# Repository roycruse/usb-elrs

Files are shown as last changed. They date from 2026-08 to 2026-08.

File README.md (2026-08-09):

# USB ELRS Receiver Dongle

> Transform an **ExpressLRS (ELRS) Receiver** and a **Seeed Studio XIAO nRF52840** into a high-speed, zero-latency USB HID Gamepad dongle for PC and laptop FPV simulators.

---

## 📌 Overview

This project turns a compact ELRS receiver (such as the Foxeer Lite ELRS RX) and a Seeed Studio XIAO nRF52840 into a permanent, plug-and-play USB HID joystick for FPV simulators (VelociDrone, Liftoff, Uncrashed, Tryp FPV, DCL, etc.).

Once plugged into your PC or laptop, it sits quietly in the background and automatically connects whenever you turn on your radio transmitter.

---

## ✨ Features

- ⚡ **Ultra-Fast Polling (1000 Hz / 1ms)**: Configured with `Adafruit_TinyUSB` for 1ms USB HID report intervals for minimum latency.
- 📡 **420k Baud CRSF Support**: Direct hardware register timing overrides (`NRF_UARTE0->BAUDRATE`) for exact 420,000 baud CRSF protocol parsing via `AlfredoCRSF`.
- 🎛️ **Full Radio Control Support (Optimized for Radiomaster GX12 / TX16S / Boxer / Pocket)**:
  - **4 Axis Sticks**: Roll, Pitch, Throttle, Yaw (CH1–CH4)
  - **2 Sliders/Dials**: S1, S2 (CH5–CH6)
  - **4 Toggle & Momentary Switches**: SA, SD, SG, SH (CH7–CH10 → HID Buttons 1–4)
  - **4 Cumulative 3-Position Switches**: SE, SB, SC, SF (CH11–CH14 → HID Buttons 5–12)
- 🟢 **Link Status LED**: Built-in green LED lights up solid when the ELRS receiver link is active.
- 🪶 **Compact & Antenna-Free**: Uses compact receiver models (like Foxeer Lite ELRS with onboard ceramic antenna) so no long external dipoles get in the way.

---

## 🛠️ Hardware Requirements

| Component | Recommendation | Notes |
| :--- | :--- | :--- |
| **Microcontroller** | Seeed Studio XIAO nRF52840 | Native USB stack & fast hardware UART |
| **ELRS Receiver** | Foxeer Lite ELRS RX (or similar) | Integrated SMD ceramic antenna; ideal for desk/room range |
| **Wiring** | 4-wire connection | Power, Ground, TX, RX |

---

## 🔌 Wiring & Pinout

Connect the ELRS receiver to the XIAO nRF52840 as follows:

| Seeed XIAO nRF52840 Pin | ELRS Receiver Pin | Description |
| :---: | :---: | :--- |
| **5V / 3V3** | **VCC** | Power Supply |
| **GND** | **GND** | Ground |
| **D5** | **TX** | XIAO Serial1 RX $\leftarrow$ Receiver TX |
| **D6** | **RX** | XIAO Serial1 TX $\rightarrow$ Receiver RX |

### 🖼️ Circuit Diagrams

<div align="center">

#### Top Side Soldering Layout
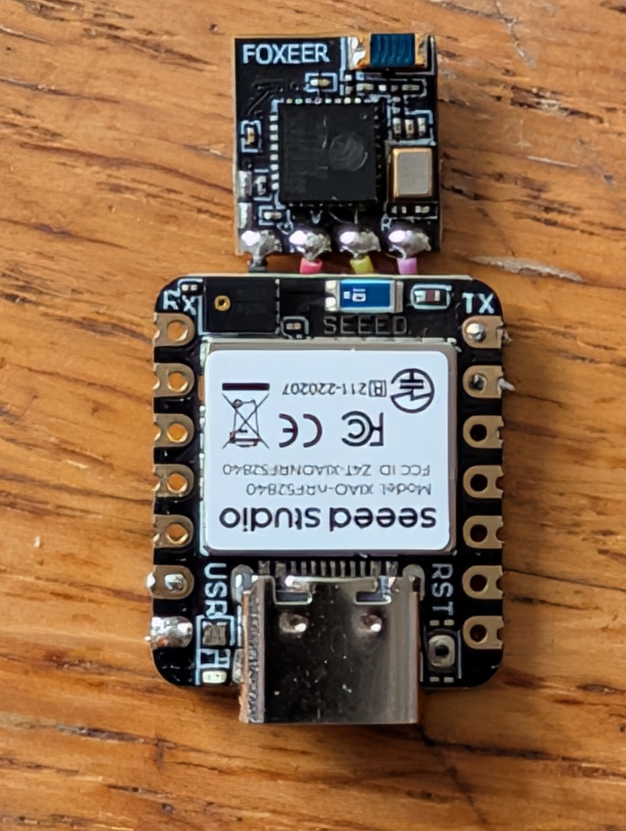
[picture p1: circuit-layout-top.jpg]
Circuit Layout Top


#### Bottom Side Soldering Layout
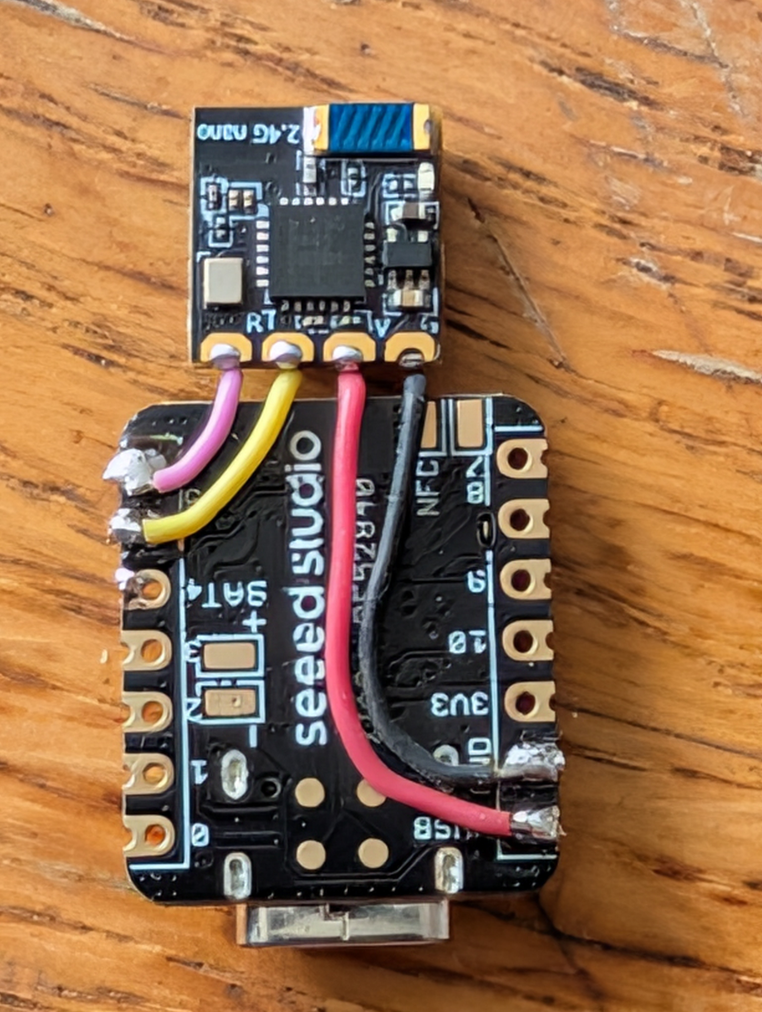
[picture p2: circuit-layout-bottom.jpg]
Circuit Layout Bottom


</div>

---

## 🕹️ Channel Mapping

| Channel | Radio Input | HID Mapping | Description |
| :---: | :---: | :---: | :--- |
| **CH1** | Roll | `X` Axis | Stick Roll (-127 to 127) |
| **CH2** | Pitch | `Y` Axis | Stick Pitch (-127 to 127) |
| **CH3** | Throttle | `Z` Axis | Stick Throttle (-127 to 127) |
| **CH4** | Yaw | `Rz` Axis | Stick Yaw (-127 to 127) |
| **CH5** | Slider S1 | `Rx` Axis | Auxiliary Slider 1 |
| **CH6** | Slider S2 | `Ry` Axis | Auxiliary Slider 2 |
| **CH7** | Switch SA | Button 1 | Toggle / Momentary Switch |
| **CH8** | Switch SD | Button 2 | Toggle / Momentary Switch |
| **CH9** | Switch SG | Button 3 | Toggle / Momentary Switch |
| **CH10** | Switch SH | Button 4 | Toggle / Momentary Switch |
| **CH11** | Switch SE | Buttons 5 & 6 | Cumulative 3-Pos Switch |
| **CH12** | Switch SB | Buttons 7 & 8 | Cumulative 3-Pos Switch |
| **CH13** | Switch SC | Buttons 9 & 10 | Cumulative 3-Pos Switch |
| **CH14** | Switch SF | Buttons 11 & 12 | Cumulative 3-Pos Switch |

> [!NOTE]
> **3-Position Switch Logic**:
> - **Pushed Away** (`< 1300µs`): Both buttons OFF
> - **Middle Position** (`1300µs – 1700µs`): Button A ON
> - **Pulled Near** (`> 1700µs`): Button A ON + Button B ON

---

## 💻 Software Setup

### Prerequisites

1. **Arduino IDE** (v2.x recommended)
2. **Seeed nRF52840 Board Support**:
   - Add Seeed nRF52840 package via Arduino Board Manager (`Seeed nRF52840 Boards`).
3. **Required Libraries**:
   - `Adafruit TinyUSB Library`
   - `AlfredoCRSF`

### Flashing

1. Select Board: **Seeed XIAO nRF52840**
2. Select USB Stack: **Adafruit TinyUSB** (*Tools > USB Stack > Adafruit TinyUSB*)
3. Open [`usb-elrs-seed-xiao-nrf52840.ino`](usb-elrs-seed-xiao-nrf52840.ino)
4. Compile and Upload!

---

## 📦 3D Printed Case & Enclosure Design

A custom 2-part protective enclosure is included in this repository to neatly house both the Seeed Studio XIAO nRF52840 and the ELRS receiver.

### Included CAD & 3D Model Files

| File | Description | Format |
| :--- | :--- | :---: |
| [`usb elrs case.f3d`](usb%20elrs%20case.f3d) | Autodesk Fusion 360 Master Parametric CAD File | `.f3d` |
| [`usb elrs case top.3mf`](usb%20elrs%20case%20top.3mf) | Top Enclosure Cover | `.3mf` |
| [`usb elrs case bottom.3mf`](usb%20elrs%20case%20bottom.3mf) | Bottom Main Housing Base | `.3mf` |

### 🖨️ Recommended Print Settings

- **Layer Height**: `0.16mm` or `0.20mm`
- **Infill**: `15% – 20%` (Gyroid or Grid)
- **Material**: PLA, PETG, or ABS/ASA
- **Supports**: None needed when printed flat on the bed

---

## 🚀 Project Status & Roadmap

- [x] High-speed 1ms USB HID joystick code for Seeed XIAO nRF52840
- [x] Full CRSF 14-channel stick, slider & switch mapping
- [x] Hardware register timing overrides for 420k baud CRSF
- [x] Custom 3D-printed protective enclosure (`.f3d` CAD source & `.3mf` models)

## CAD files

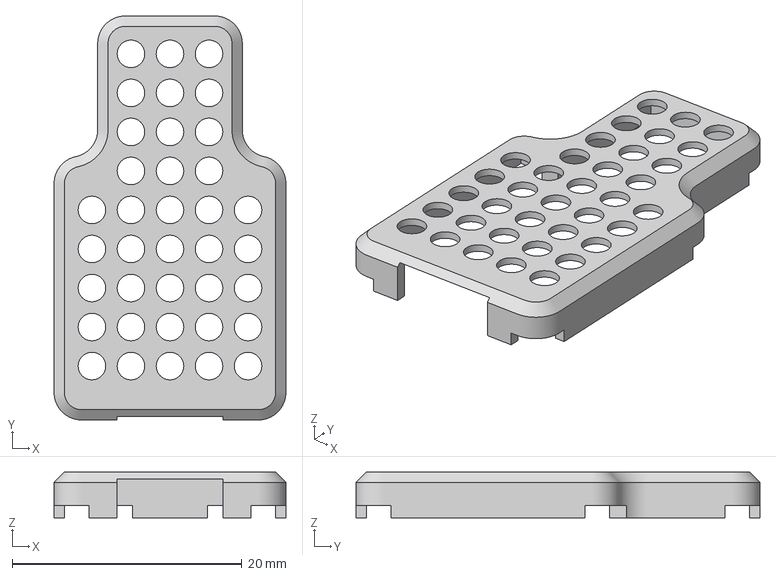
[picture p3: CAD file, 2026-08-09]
usb elrs case top.3mf
20.2 x 35.2 x 4.00 mm

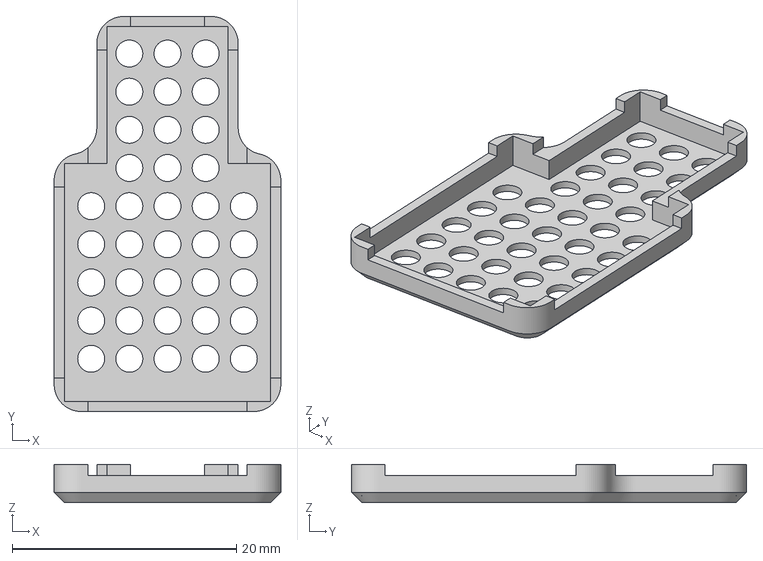
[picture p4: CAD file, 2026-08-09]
usb elrs case bottom.3mf
20.2 x 35.2 x 3.40 mm

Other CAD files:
usb elrs case.f3d

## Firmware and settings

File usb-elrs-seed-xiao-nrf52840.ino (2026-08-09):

#include <Arduino.h>
#include <Adafruit_TinyUSB.h>
#include <AlfredoCRSF.h>

// Standard Gamepad HID Descriptor
uint8_t const desc_hid_report[] = {
  TUD_HID_REPORT_DESC_GAMEPAD()
};

Adafruit_USBD_HID usb_hid;

typedef struct ATTR_PACKED {
  int8_t  x;         // CH1: Roll
  int8_t  y;         // CH2: Pitch
  int8_t  z;         // CH3: Throttle
  int8_t  rz;        // CH4: Yaw
  int8_t  rx;        // CH5: Slider S1
  int8_t  ry;        // CH6: Slider S2
  uint8_t hat;       // Hat switch (0 = centered)
  uint32_t buttons;  // Bitfield for Buttons 1-12 (CH7-CH14)
} hid_custom_gamepad_report_t;

hid_custom_gamepad_report_t gp;
AlfredoCRSF crsf;

void setup() {
  pinMode(LED_GREEN, OUTPUT);
  digitalWrite(LED_GREEN, HIGH); // Off initially

  // Ultra-fast 1ms USB HID polling rate
  usb_hid.setPollInterval(1);
  usb_hid.setReportDescriptor(desc_hid_report, sizeof(desc_hid_report));
  usb_hid.begin();

  // Hardware UART on D5 (RX) / D6 (TX)
  Serial1.setPins(D5, D6);
  Serial1.begin(420000);
  NRF_UARTE0->BAUDRATE = 0x06B50000; // Exact 420k timing override

  crsf.begin(Serial1);
  memset(&gp, 0, sizeof(gp));
}

void loop() {
  crsf.update();

  if (crsf.isLinkUp()) {
    digitalWrite(LED_GREEN, LOW); // Green LED ON solid when linked

    // --- 1. STICKS (CH1 - CH4) ---
    gp.x  = (int8_t)map(constrain(crsf.getChannel(1), 988, 2012), 988, 2012, -127, 127);
    gp.y  = (int8_t)map(constrain(crsf.getChannel(2), 988, 2012), 988, 2012, -127, 127);
    gp.z  = (int8_t)map(constrain(crsf.getChannel(3), 988, 2012), 988, 2012, -127, 127);
    gp.rz = (int8_t)map(constrain(crsf.getChannel(4), 988, 2012), 988, 2012, -127, 127);

    // --- 2. SLIDERS / DIALS (CH5 & CH6) ---
    gp.rx = (int8_t)map(constrain(crsf.getChannel(5), 988, 2012), 988, 2012, -127, 127);
    gp.ry = (int8_t)map(constrain(crsf.getChannel(6), 988, 2012), 988, 2012, -127, 127);

    uint32_t btnState = 0;

    // --- 3. TOGGLES & MOMENTARIES (CH7 - CH10 -> Buttons 1 to 4) ---
    // SA, SD, SG, SH: High (>1500us) turns on single button
    if (crsf.getChannel(7)  > 1500) btnState |= (1UL << 0); // Button 1 (SA)
    if (crsf.getChannel(8)  > 1500) btnState |= (1UL << 1); // Button 2 (SD)
    if (crsf.getChannel(9)  > 1500) btnState |= (1UL << 2); // Button 3 (SG)
    if (crsf.getChannel(10) > 1500) btnState |= (1UL << 3); // Button 4 (SH)

    // --- 4. CUMULATIVE 3-POS SWITCHES (CH11 - CH14 -> Buttons 5 to 12) ---
    // SE, SB, SC, SF:
    // Pushed Away (<1300us)   -> Off (No buttons)
    // Middle      (1300-1700) -> Button A ON
    // Pulled Near (>1700us)   -> Button A ON + Button B ON
    uint8_t btnIndex = 4; // Start at Button 5 bit offset

    for (uint8_t ch = 11; ch <= 14; ch++) {
      int val = crsf.getChannel(ch);

      if (val >= 1300 && val <= 1700) {
        // Mid position: Turn on first button
        btnState |= (1UL << btnIndex);
      } 
      else if (val > 1700) {
        // Fully pulled position: Keep first button ON AND turn on second button
        btnState |= (1UL << btnIndex);
        btnState |= (1UL << (btnIndex + 1));
      }
      // If val < 1300 (pushed away), neither bit is set (Off)

      btnIndex += 2; // Allocate 2 button bits per 3-pos switch
    }

    gp.buttons = btnState;

    if (usb_hid.ready()) {
      usb_hid.sendReport(0, &gp, sizeof(gp));
    }
  } else {
    digitalWrite(LED_GREEN, HIGH); // Off if link drops
  }
}

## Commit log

2026-08-09 feat: add CRSF to HID gamepad firmware and circuit documentation for Seeed XIAO nRF52840
2026-08-09 docs: rewrite README with comprehensive project documentation, wiring diagrams, and setup instructions
2026-08-09 feat: add 3D-printed enclosure CAD files and update project documentation
    [usb elrs case bottom.3mf, usb elrs case top.3mf, usb elrs case.f3d]
